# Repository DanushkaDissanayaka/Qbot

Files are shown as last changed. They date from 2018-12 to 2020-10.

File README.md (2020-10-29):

# Qbot
Arduino based multi funtional micro bot( 115mm)

## Built With

* [Arduino Mega](https://www.arduino.cc/) - single-board microcontrollers and microcontroller kit
## Demo video
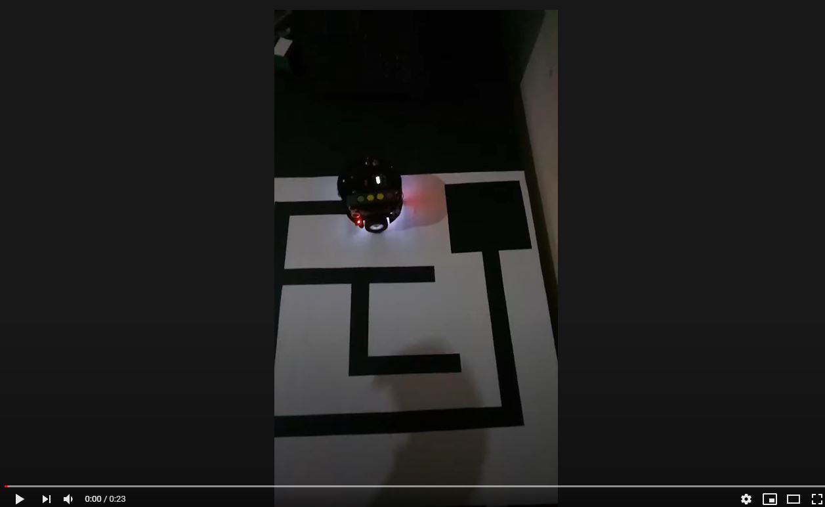
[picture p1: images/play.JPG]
Watch the video (https://youtu.be/nKPnC0TbPwI)

## Robot Snapshot
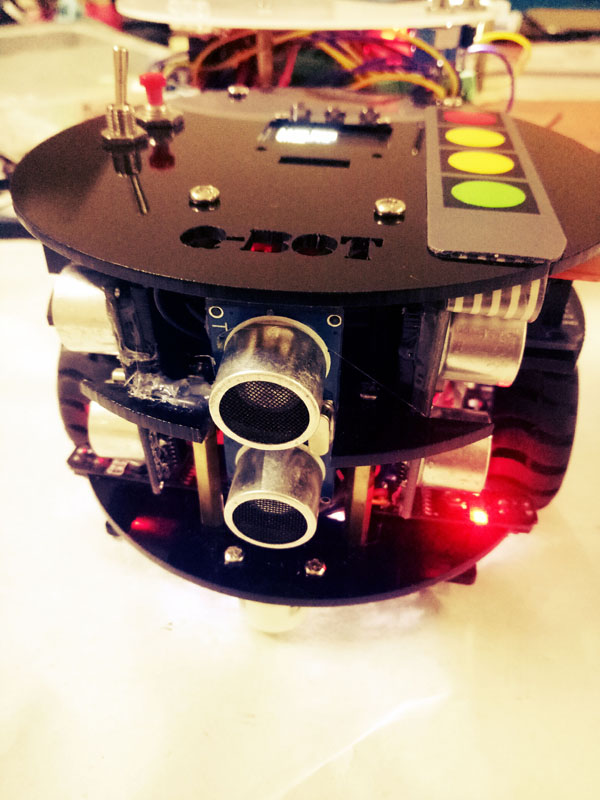
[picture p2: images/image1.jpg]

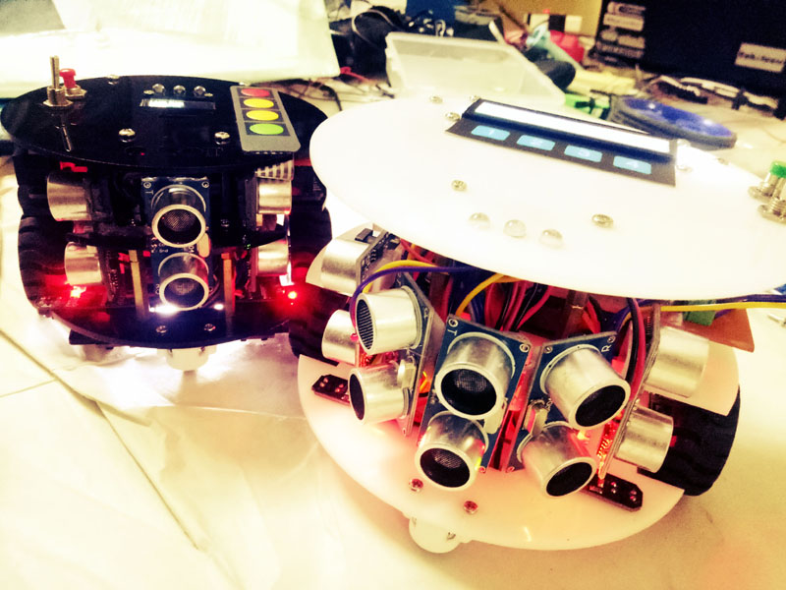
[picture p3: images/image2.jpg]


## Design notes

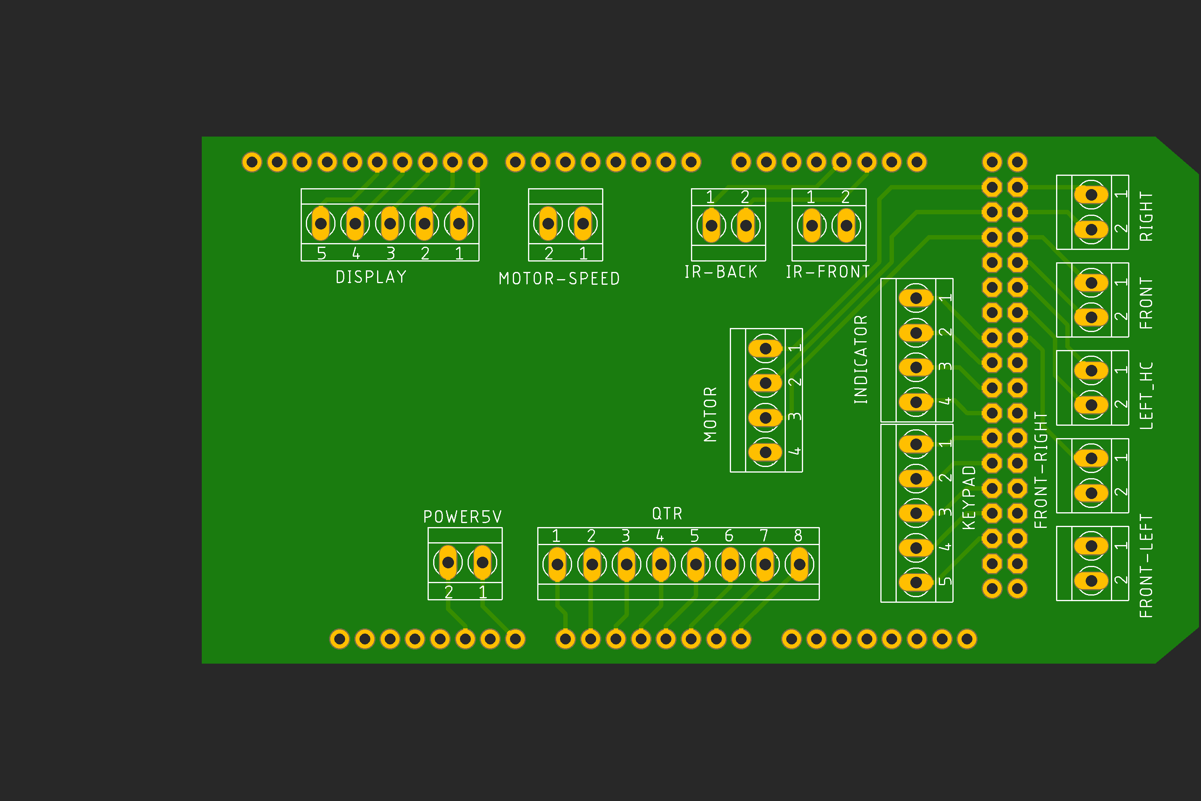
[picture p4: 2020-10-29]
images/SheeldV3.png

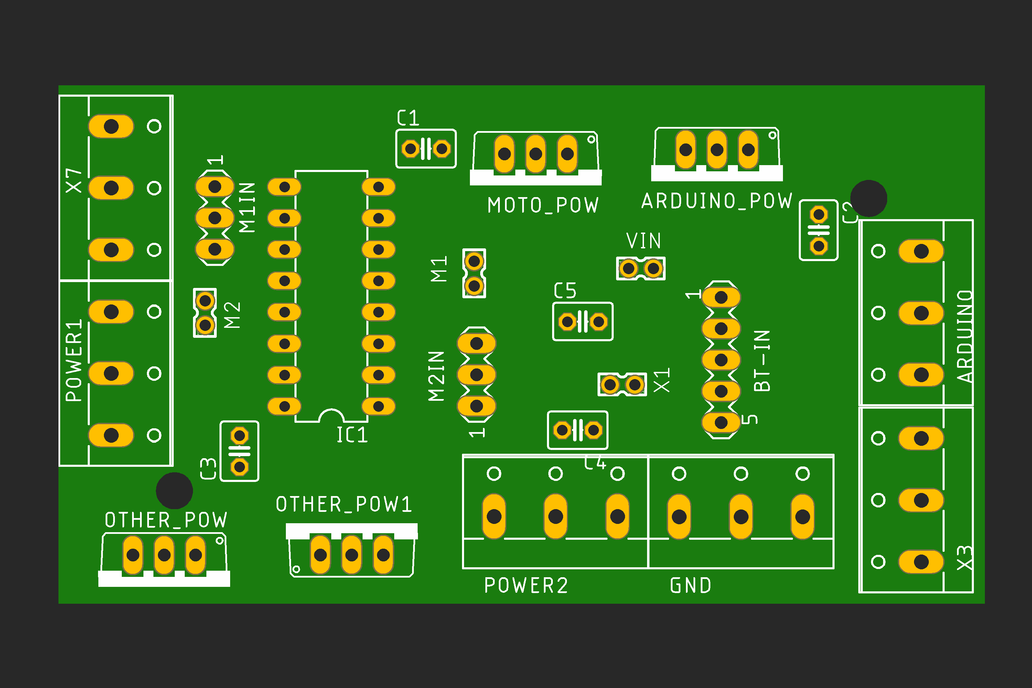
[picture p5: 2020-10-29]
images/Moror_Driver_and_Power_Board_v2.png

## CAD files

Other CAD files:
StructureDesighn/base design.dwg

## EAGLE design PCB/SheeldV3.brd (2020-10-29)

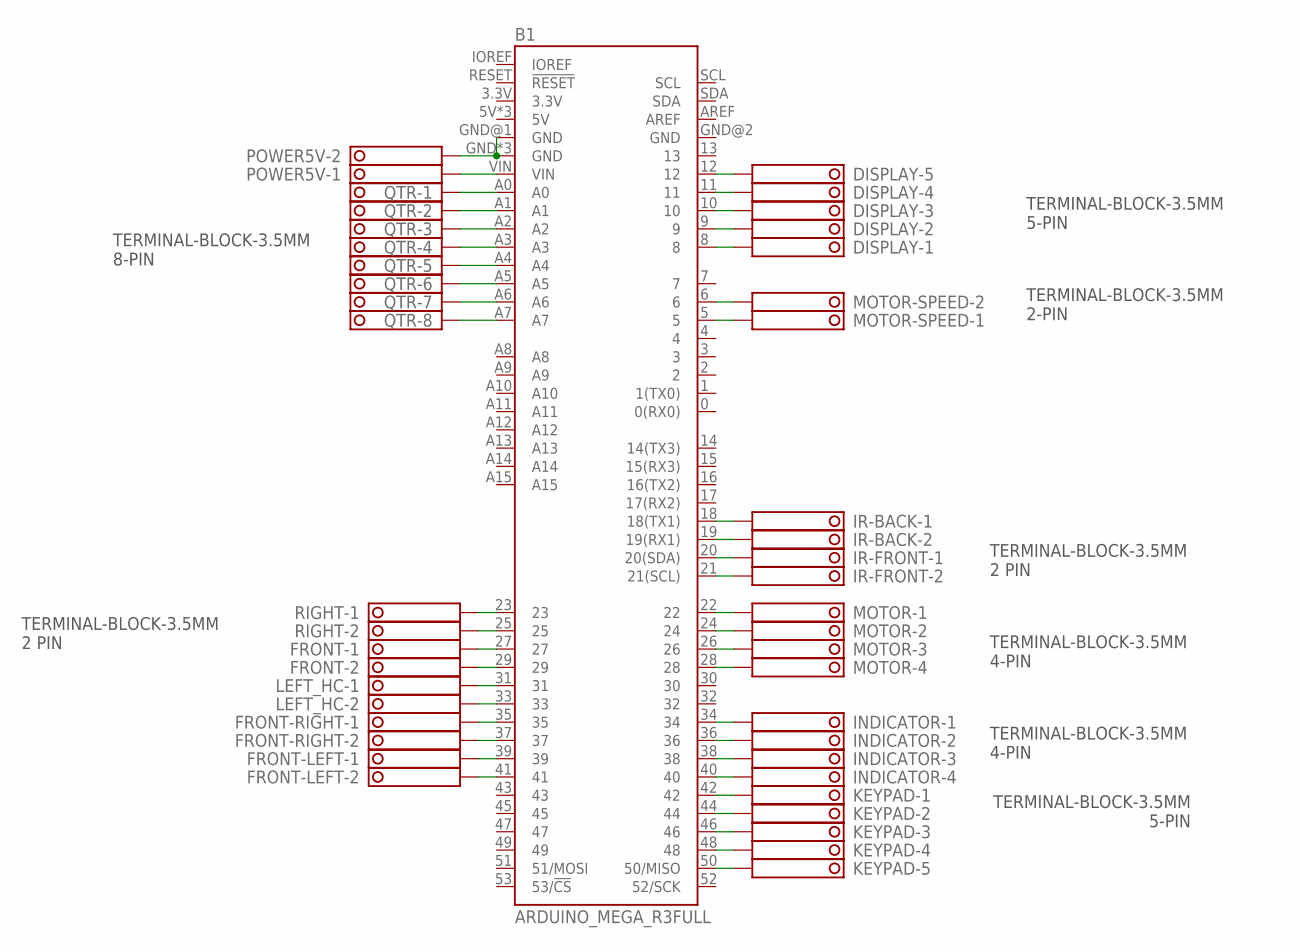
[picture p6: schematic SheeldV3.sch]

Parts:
B1: ARDUINO_MEGA_R3FULL; ARDUINO_MEGA_NO_SILK
DISPLAY: TERMINAL-BLOCK-3.5MM-5-PIN-LONG-PAD; TERMINAL-BLOCK-5-PIN-3.5MM-LONG-PAD
FRONT: TERMINAL-BLOCK-3.5MM-2-PIN-LONG-PAD; TERMINAL-BLOCK-2-PIN-3.5MM-LONG-PAD
FRONT-LEFT: TERMINAL-BLOCK-3.5MM-2-PIN-LONG-PAD; TERMINAL-BLOCK-2-PIN-3.5MM-LONG-PAD
FRONT-RIGHT: TERMINAL-BLOCK-3.5MM-2-PIN-LONG-PAD; TERMINAL-BLOCK-2-PIN-3.5MM-LONG-PAD
INDICATOR: TERMINAL-BLOCK-3.5MM-4-PIN-LONG-PAD; TERMINAL-BLOCK-4-PIN-3.5MM-LONG-PAD
IR-BACK: TERMINAL-BLOCK-3.5MM-2-PIN-LONG-PAD; TERMINAL-BLOCK-2-PIN-3.5MM-LONG-PAD
IR-FRONT: TERMINAL-BLOCK-3.5MM-2-PIN-LONG-PAD; TERMINAL-BLOCK-2-PIN-3.5MM-LONG-PAD
KEYPAD: TERMINAL-BLOCK-3.5MM-5-PIN-LONG-PAD; TERMINAL-BLOCK-5-PIN-3.5MM-LONG-PAD
LEFT_HC: TERMINAL-BLOCK-3.5MM-2-PIN-LONG-PAD; TERMINAL-BLOCK-2-PIN-3.5MM-LONG-PAD
MOTOR: TERMINAL-BLOCK-3.5MM-4-PIN-LONG-PAD; TERMINAL-BLOCK-4-PIN-3.5MM-LONG-PAD
MOTOR-SPEED: TERMINAL-BLOCK-3.5MM-2-PIN-LONG-PAD; TERMINAL-BLOCK-2-PIN-3.5MM-LONG-PAD
POWER5V: TERMINAL-BLOCK-3.5MM-2-PIN-LONG-PAD; TERMINAL-BLOCK-2-PIN-3.5MM-LONG-PAD
QTR: TERMINAL-BLOCK-3.5MM-8-PIN-LONG-PAD; TERMINAL-BLOCK-8-PIN-3.5MM-LONG-PAD
RIGHT: TERMINAL-BLOCK-3.5MM-2-PIN-LONG-PAD; TERMINAL-BLOCK-2-PIN-3.5MM-LONG-PAD

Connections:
unnamed: B1.12, DISPLAY.5
unnamed: B1.11, DISPLAY.4
unnamed: B1.10, DISPLAY.3
unnamed: B1.9, DISPLAY.2
unnamed: B1.8, DISPLAY.1
unnamed: B1.VIN, POWER5V.1
unnamed: B1.23, RIGHT.1
unnamed: B1.25, RIGHT.2
unnamed: B1.27, FRONT.1
unnamed: B1.29, FRONT.2
unnamed: B1.31, LEFT_HC.1
unnamed: B1.33, LEFT_HC.2
unnamed: B1.35, FRONT-RIGHT.1
unnamed: B1.37, FRONT-RIGHT.2
unnamed: B1.39, FRONT-LEFT.1
unnamed: B1.41, FRONT-LEFT.2
unnamed: B1.42, KEYPAD.1
unnamed: B1.44, KEYPAD.2
unnamed: B1.46, KEYPAD.3
unnamed: B1.48, KEYPAD.4
unnamed: B1.50 (50/MISO), KEYPAD.5
unnamed: B1.22, MOTOR.1
unnamed: B1.24, MOTOR.2
unnamed: B1.26, MOTOR.3
unnamed: B1.28, MOTOR.4
unnamed: B1.34, INDICATOR.1
unnamed: B1.36, INDICATOR.2
unnamed: B1.38, INDICATOR.3
unnamed: B1.40, INDICATOR.4
unnamed: B1.6, MOTOR-SPEED.2
unnamed: B1.5, MOTOR-SPEED.1
unnamed: B1.21 (21(SCL)), IR-FRONT.2
unnamed: B1.20 (20(SDA)), IR-FRONT.1
unnamed: B1.19 (19(RX1)), IR-BACK.2
unnamed: B1.18 (18(TX1)), IR-BACK.1
unnamed: B1.GND, B1.GND@1 (GND), B1.GND@3 (GND), B1.GND@4 (GND), POWER5V.2
unnamed: B1.A0, QTR.1
unnamed: B1.A1, QTR.2
unnamed: B1.A2, QTR.3
unnamed: B1.A3, QTR.4
unnamed: B1.A4, QTR.5
unnamed: B1.A5, QTR.6
unnamed: B1.A6, QTR.7
unnamed: B1.A7, QTR.8

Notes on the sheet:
TERMINAL-BLOCK-3.5MM 2 PIN
TERMINAL-BLOCK-3.5MM 4-PIN
TERMINAL-BLOCK-3.5MM 5-PIN
TERMINAL-BLOCK-3.5MM 2-PIN
TERMINAL-BLOCK-3.5MM 8-PIN

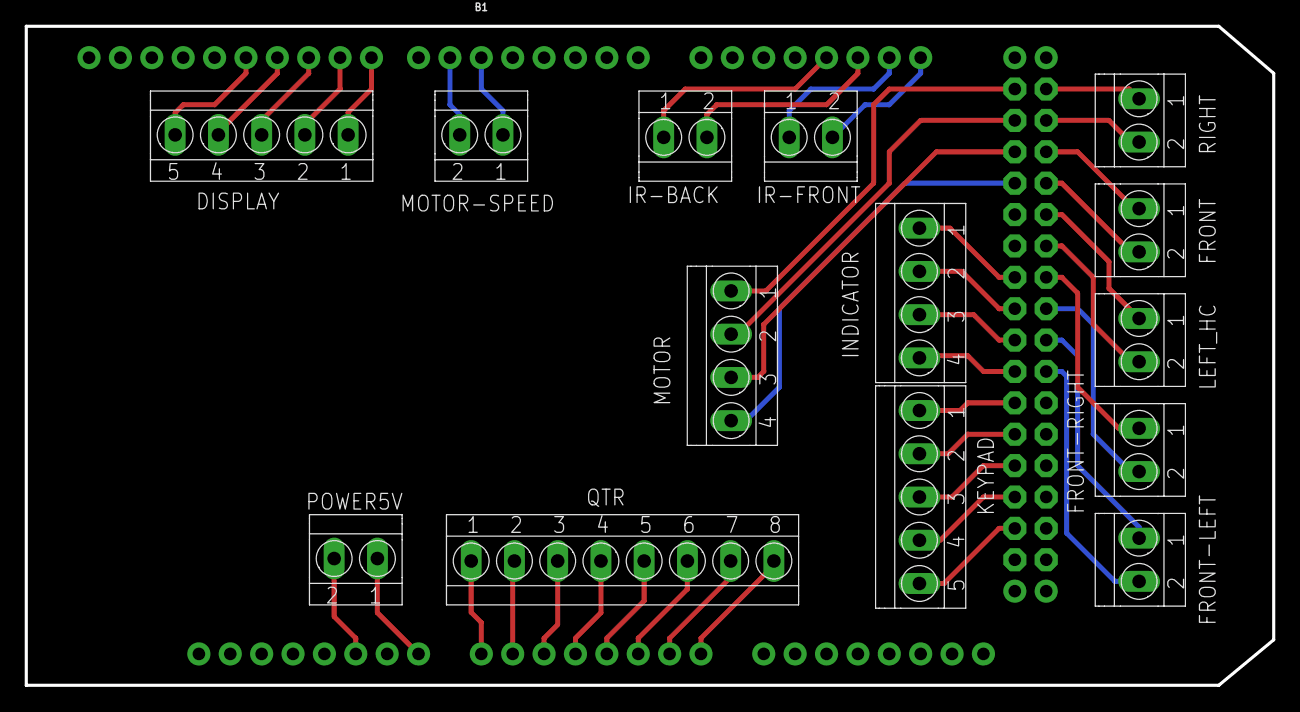
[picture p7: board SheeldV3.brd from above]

Board: 2 copper layers, 101.0 x 53.3 mm, 15 parts (0 on the bottom side), 44 nets.

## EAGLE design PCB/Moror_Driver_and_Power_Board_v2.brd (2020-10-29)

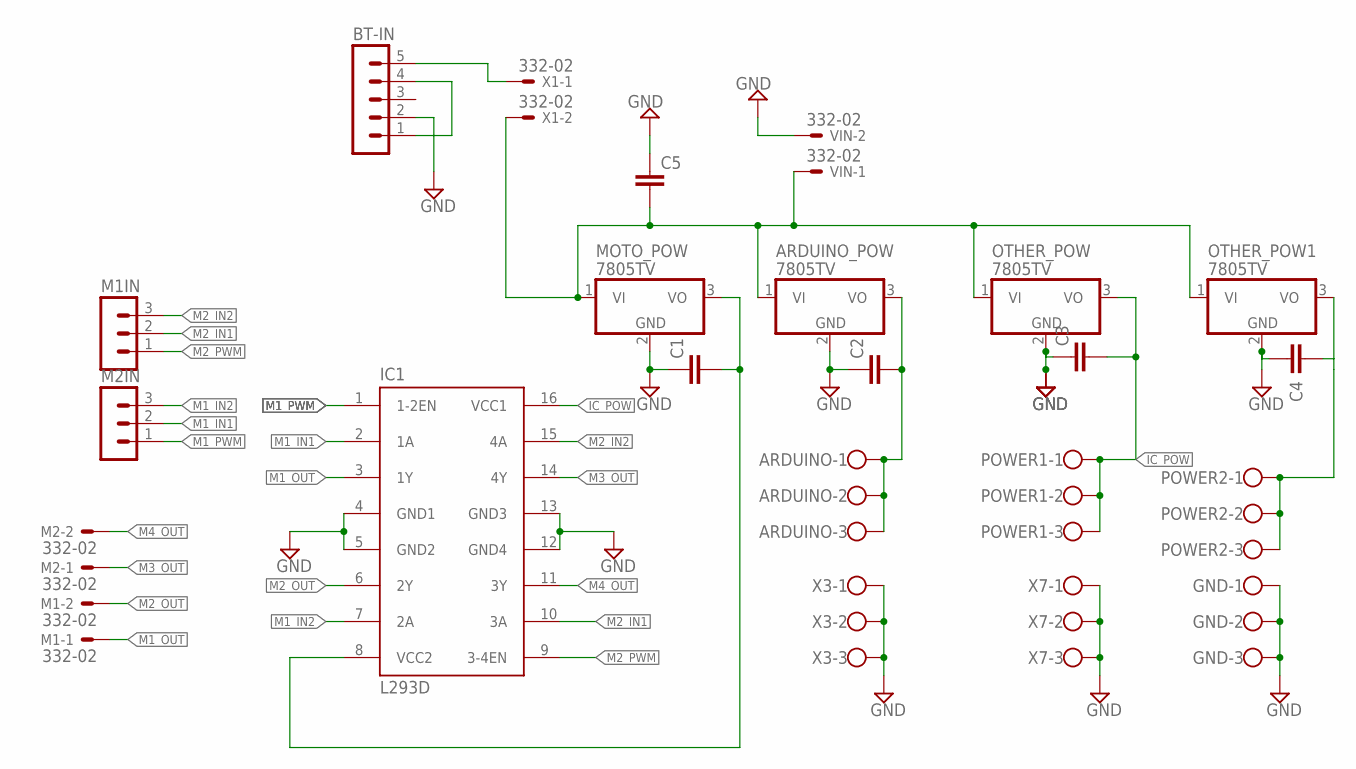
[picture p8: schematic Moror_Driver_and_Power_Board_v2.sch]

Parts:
ARDUINO: W237-103
ARDUINO_POW: 7805TV; TO220V
BT-IN: MA05-1
C1, C2, C3, C4, C5: C-EU025-030X050; C025-030X050
GND: W237-103
IC1: L293D; DIL16
M1, M2: 332-02
M1IN, M2IN: MA03-1
MOTO_POW: 7805TV; TO220V
OTHER_POW, OTHER_POW1: 7805TV; TO220V
POWER1, POWER2: W237-103
VIN: 332-02
X1: 332-02
X3, X7: W237-103

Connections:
GND: ARDUINO_POW.2 (GND), BT-IN.2, C1.1, C2.1, C3.1, C4.1, C5.1, GND.1, GND.2, GND.3, IC1.4 (GND1), IC1.5 (GND2), IC1.12 (GND4), IC1.13 (GND3), MOTO_POW.2 (GND), OTHER_POW.2 (GND), OTHER_POW1.2 (GND), VIN.2, X3.1, X3.2, X3.3, X7.1, X7.2, X7.3
IC_POW: C3.2, IC1.16 (VCC1), OTHER_POW.3 (VO), POWER1.1, POWER1.2, POWER1.3
M1_IN1: IC1.2 (1A), M2IN.2
M1_IN2: IC1.7 (2A), M2IN.3
M1_OUT: IC1.3 (1Y), M1.1
M1_PWM: IC1.1 (1-2EN), M2IN.1
M2_IN1: IC1.10 (3A), M1IN.2
M2_IN2: IC1.15 (4A), M1IN.3
M2_OUT: IC1.6 (2Y), M1.2
M2_PWM: IC1.9 (3-4EN), M1IN.1
M3_OUT: IC1.14 (4Y), M2.1
M4_OUT: IC1.11 (3Y), M2.2
unnamed: ARDUINO_POW.1 (VI), C5.2, MOTO_POW.1 (VI), OTHER_POW.1 (VI), OTHER_POW1.1 (VI), VIN.1, X1.2
unnamed: BT-IN.1, BT-IN.4
unnamed: BT-IN.5, X1.1
unnamed: C1.2, IC1.8 (VCC2), MOTO_POW.3 (VO)
unnamed: C4.2, OTHER_POW1.3 (VO), POWER2.1, POWER2.2, POWER2.3
VCC: ARDUINO.1, ARDUINO.2, ARDUINO.3, ARDUINO_POW.3 (VO), C2.2

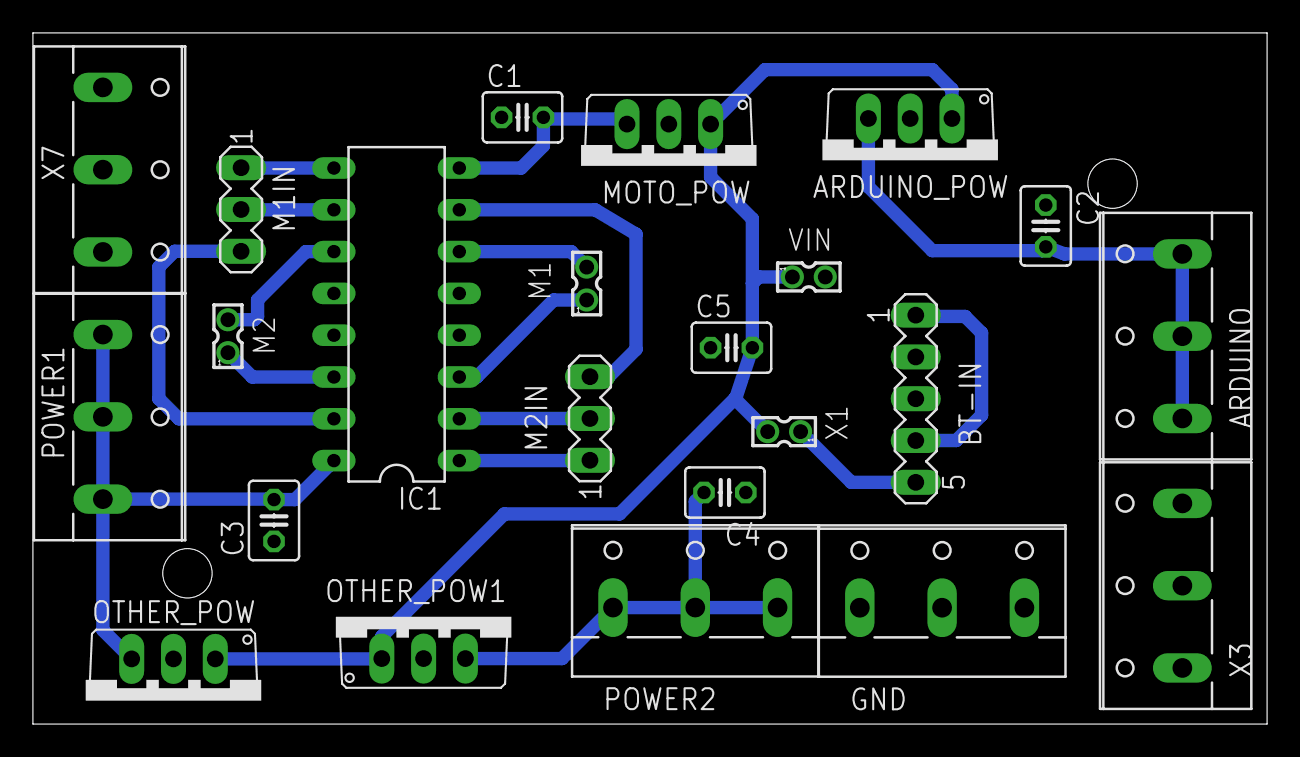
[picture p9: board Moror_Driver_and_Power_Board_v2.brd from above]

Board: 2 copper layers, 75.0 x 42.0 mm, 23 parts (0 on the bottom side), 18 nets.

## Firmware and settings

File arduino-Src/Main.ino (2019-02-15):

#include "distanceSensor.h"
#include "indicators.h" // no need to include allradey in QTRSensor.h
#include "motor.h" // no need to include allradey in lineFollow.h
#include "QTRSensor.h" // no need to include allradey in lineFollow.h
#include "lineFollow.h"
#include "wallFollow.h"
#include "keyPad.h"
#include "dispaly.h"
#include "menu.h"
#include "irSensor.h"
#include "mazeSolve.h"

void setup() {
    sensorInit();
    indicatorsInit();
    Serial.begin(115200);
    keypadInit();
    dispalyInit();
    displayMainMenu();
    irSensorInit();
    // calibrateSensorArray();
    //delay(5000);
}

void loop() {
    // testparts();
    withMenu();
}

void doTask(){

    fullSpeedLineFollowBlackStrip();
    delay(100);
    Stop();
    fullSpeedLineFollowWhiteStrip();
    fullSpeedLineFollowWhiteStrip();
    Stop();
    speedControl(255,255);
    turnLeft();
    delay(150);
    Stop();
    fullSpeedLineFollowWhiteStrip();
}

void testparts(void){
    // testIndicators();
    testDistanceSensor();
    // testMotors();
    // testSensorArray();
    // fullSpeedLineFollowBlackStrip();
    // fullSpeedRightWallFollow();
    // displayTest();
    // testIrSensor();
}

void withMenu(void){
    char key = getKey();

 if(key != 'n'){

     if(key == 's' ){
         displayLIneFllow();
         LineFollowMenu();
         displayMainMenu();
        }

        if(key == 'b' ){
            displayText("Tuning");
            calibrateSensorArray();
            displayMainMenu();
        }

        if(key == 'u' ){
            displayWallFllow();
            WallFollowMenu();
            // BlackLineTurnRight();
            displayMainMenu();
        }

        if(key == 'd' ){
            displayText("solving maze");
            solveMaze();
            displayMainMenu();
        }
 }
}

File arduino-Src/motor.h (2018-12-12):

#ifndef motor_h
  #define motor_h
  #define leftPin1  24 // arudino out put pin for motor driver 5-11 this pin will drive wheel motor
  #define leftPin2  22
  #define speedPinLeft 5
  #define rightPin1 26
  #define rightPin2 28
  #define speedPinRight 6 


  #define FULL_MOTOR_SPEED_LEFT   255
  #define FULL_MOTOR_SPEED_RIGHT  255
  #define FULL_BASE_SPEED_RIGHT   200
  #define FULL_BASE_SPEED_LEFT    200

  #define WALL_MOTOR_SPEED_LEFT   200
  #define WALL_MOTOR_SPEED_RIGHT  200
  #define WALL_BASE_SPEED_RIGHT   140
  #define WALL_BASE_SPEED_LEFT    140

  #define  halfMotorSpeed  180
  #define  halfBaseSpeed   120

  #define STOP_SPEED  10
  #define BREAK_DELAY 80

  #define ROTATION_90         300
  #define ROTATION_180        500
  
  int    leftMotorSpeed  = 0;
  int    rightMotorSpeed = 0;

  void motorInit (){
      pinMode(leftPin1, OUTPUT);
      pinMode(leftPin2, OUTPUT);
      pinMode(rightPin1, OUTPUT);
      pinMode(rightPin2, OUTPUT);
      pinMode(speedPinLeft, OUTPUT);
      pinMode(speedPinRight, OUTPUT);
  }

    void speedControl (uint16_t lSpeed , uint16_t rSpeed){
    analogWrite(speedPinLeft, lSpeed);
    analogWrite(speedPinRight, rSpeed);
  }

   void normalSpeed(void){
    analogWrite (speedPinLeft, 120);
    analogWrite (speedPinRight, 162);
  }

  void forward(void){
    digitalWrite (leftPin1, HIGH);
    digitalWrite (leftPin2, LOW);
    digitalWrite (rightPin1, HIGH);
    digitalWrite (rightPin2, LOW);
  }

  void backward(void){
    digitalWrite (leftPin1, LOW);
    digitalWrite (leftPin2, HIGH);
    digitalWrite (rightPin1, LOW);
    digitalWrite (rightPin2, HIGH);
  }

  void turnRight(void){
    digitalWrite (leftPin1, LOW);
    digitalWrite (leftPin2, HIGH);
    digitalWrite (rightPin1, HIGH);
    digitalWrite (rightPin2, LOW);
  }

  void turnLeft(void){
    digitalWrite (leftPin1, HIGH);
    digitalWrite (leftPin2, LOW);
    digitalWrite (rightPin1, LOW);
    digitalWrite (rightPin2, HIGH);
  }

  void Stop (void){
    speedControl(STOP_SPEED,STOP_SPEED);
    digitalWrite (leftPin1, LOW);
    digitalWrite (leftPin2, LOW);
    digitalWrite (rightPin1, LOW);
    digitalWrite (rightPin2, LOW);
  }

  void freeforward (uint16_t time){
    normalSpeed();
    forward();
    delay(time);
    Stop();
  }

  void freeBackward (void){
    normalSpeed();
    backward();
  }

  void FreeRotateLeft(uint16_t time){
    normalSpeed();
    turnLeft();
    delay(time);
    Stop();
  }

  void FreeRotateRight(uint16_t time){
    normalSpeed();
    turnRight();
    delay(time);
    Stop();
  }

  void ForwordBreak(void){
    speedControl(255,255);
    backward();
    delay(BREAK_DELAY);
    Stop(); // stop both motors after line Follow
  }

  void testMotors(){
      /*speedControl (255 ,100);
      forward();
      delay(1000);
      Stop();
      backward();
      delay(1000);
      Stop();*/

      forward();

      for(uint16_t i = 0; i < 256; i++)
      {
        speedControl (i ,0);
        delay(100);
      }

      for(uint16_t i = 0; i < 256; i++)
      {
        speedControl (0 ,i);
        delay(100);
      }
      
  }
#endif

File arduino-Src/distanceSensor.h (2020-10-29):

#ifndef  distanceSensor_h
    #define distanceSensor_h
    #define MAX_DISTANCE        2000 // In micro second
    #define LEFT_ECHO_PIN       31
    #define LEFT_TRIG_PIN       33

    #define RIGHT_ECHO_PIN      23
    #define RIGHT_TRIG_PIN      25

    #define FRONT_RIGHT_ECHO_PIN      35
    #define FRONT_RIGHT_TRIG_PIN      37

    #define FRONT_LEFT_ECHO_PIN      39
    #define FRONT_LEFT_TRIG_PIN      41

    #define FRONT_ECHO_PIN      27
    #define FRONT_TRIG_PIN      29

    #define LEFT        1
    #define RIGHT       2
    #define FRONT       3
    #define FRONT_RIGHT 4
    #define FRONT_LEFT  5

    void sensorInit(){
        pinMode(LEFT_TRIG_PIN,OUTPUT);
        pinMode(LEFT_ECHO_PIN,INPUT);

        pinMode(RIGHT_TRIG_PIN,OUTPUT);
        pinMode(RIGHT_ECHO_PIN,INPUT);

        pinMode(FRONT_TRIG_PIN,OUTPUT);
        pinMode(FRONT_ECHO_PIN,INPUT);

        pinMode(FRONT_RIGHT_TRIG_PIN,OUTPUT);
        pinMode(FRONT_RIGHT_ECHO_PIN,INPUT);

        pinMode(FRONT_LEFT_TRIG_PIN,OUTPUT);
        pinMode(FRONT_LEFT_ECHO_PIN,INPUT);
    }

    void createPulse(uint8_t pin){
        digitalWrite(pin,LOW);
        delayMicroseconds(2);
        digitalWrite(pin,HIGH);
        delayMicroseconds(10);
        digitalWrite(pin,LOW);
    }

    unsigned int getDistance(uint8_t side){
        
        switch (side)
        {
            case LEFT:
                createPulse(LEFT_TRIG_PIN);
                return pulseIn(LEFT_ECHO_PIN,HIGH,MAX_DISTANCE)/29/2;
                // get Left Distance

            case RIGHT:
                createPulse(RIGHT_TRIG_PIN);
                return pulseIn(RIGHT_ECHO_PIN,HIGH,MAX_DISTANCE)/29/2;
                // get Right Distance
                
            case FRONT:
                createPulse(FRONT_TRIG_PIN);
                return pulseIn(FRONT_ECHO_PIN,HIGH,MAX_DISTANCE)/29/2;
                // get Front Distance

            case FRONT_RIGHT:
                createPulse(FRONT_RIGHT_TRIG_PIN);
                return pulseIn(FRONT_RIGHT_ECHO_PIN,HIGH)/29/2;
                // get FRONT_RIGHT Distance

            case FRONT_LEFT:
                createPulse(FRONT_LEFT_TRIG_PIN);
                return pulseIn(FRONT_LEFT_ECHO_PIN,HIGH)/29/2;
                // get FRONT_Left Distance

            default:
                // do noting
                return -1;
        }
    }

    void testDistanceSensor(){

        Serial.print("Distance "); 
        Serial.print('\t'); Serial.print("LEFT: "); Serial.print(getDistance(LEFT));
        Serial.print('\t'); Serial.print("FRONT: "); Serial.print(getDistance(FRONT));
        Serial.print('\t'); Serial.print("RIGHT: "); Serial.print(getDistance(RIGHT));
        Serial.print('\t'); Serial.print("FRONT RIGHT: "); Serial.print(getDistance(FRONT_RIGHT));
        Serial.print('\t'); Serial.print("FRONT LEFT: "); Serial.print(getDistance(FRONT_LEFT));
        Serial.println();
    }
#endif

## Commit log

2018-11-30 Init Commit
    [base design.dwg, base design.dxf, base design_recover.dwg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]
2018-12-10 Bigin wallfllow
    [base design.dwg]
2019-02-15 Code corrected and finalized wallfallow
    [Main.ino]
2020-10-29 PCB design added
    [Moror_Driver_and_Power_Board_v2.brd, Moror_Driver_and_Power_Board_v2.sch, SheeldV3.brd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]

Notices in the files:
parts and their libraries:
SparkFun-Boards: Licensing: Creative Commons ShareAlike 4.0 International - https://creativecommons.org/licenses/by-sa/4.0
